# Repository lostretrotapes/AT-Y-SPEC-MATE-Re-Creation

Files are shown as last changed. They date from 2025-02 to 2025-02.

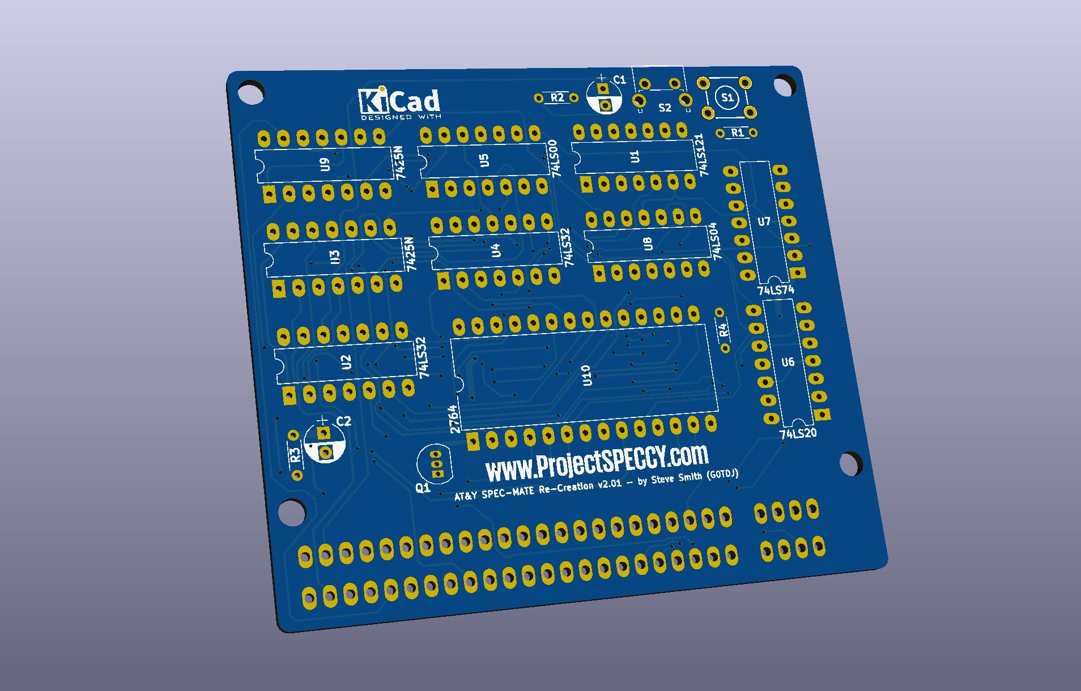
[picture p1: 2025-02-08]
images/Spec-Mate V2.01_FRONT.jpg

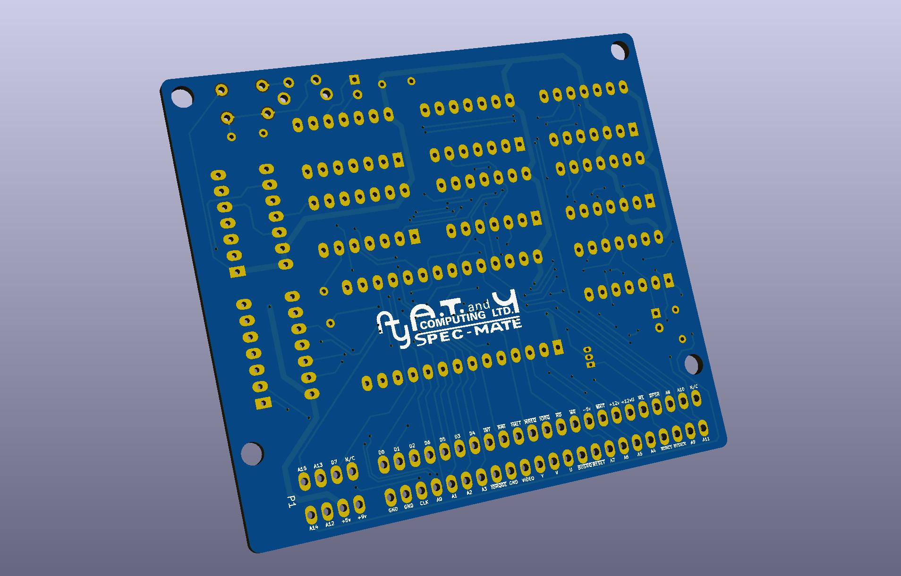
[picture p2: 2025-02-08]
images/Spec-Mate V2.01_BACK.jpg

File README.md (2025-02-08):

# AT-Y-SPEC-MATE-Re-Creation

This is a copy of the recreation that used be hosted at http://projectspeccy.com/projects/ with permission from Steve Smith

Back in the heyday of the Sinclair Spectrum and other 8-bit computers that kick started the home computing movement, I owned a Sinclair Spectrum 48K Plus that I upgraded from my original rubber key Spectrum with a kit from Sinclair. Along with my friends help, I used to hack games for infinite lives etc. This was a very common practice made easier by certian interfaces. The interfaces would freeze the game/program you were running and allow it to be saved to some sort of media, Tape, Sinclair’s own Microdrive or floppy disc for example.

Of course, these interfaces were quite expensive and above the budget of your average schoolboy hacker! I used to hack long-hand, that is to say, from the loader up. Some programs defeated my limited knowledge. Handily though, I had a friend who was into computers and had a more affluent family than I. He got a SPEC-MATE for his birthday. Later on, he loaned it to me so I could capture my game collection to Tape/Microdrive. This was a revelation! And one of the really useful features was that the SPEC-MATE made two files of main memory. This meant that you could load a dissassembler into one part of memory and a half of the programs code in the other. Hacking became exponentially easier!

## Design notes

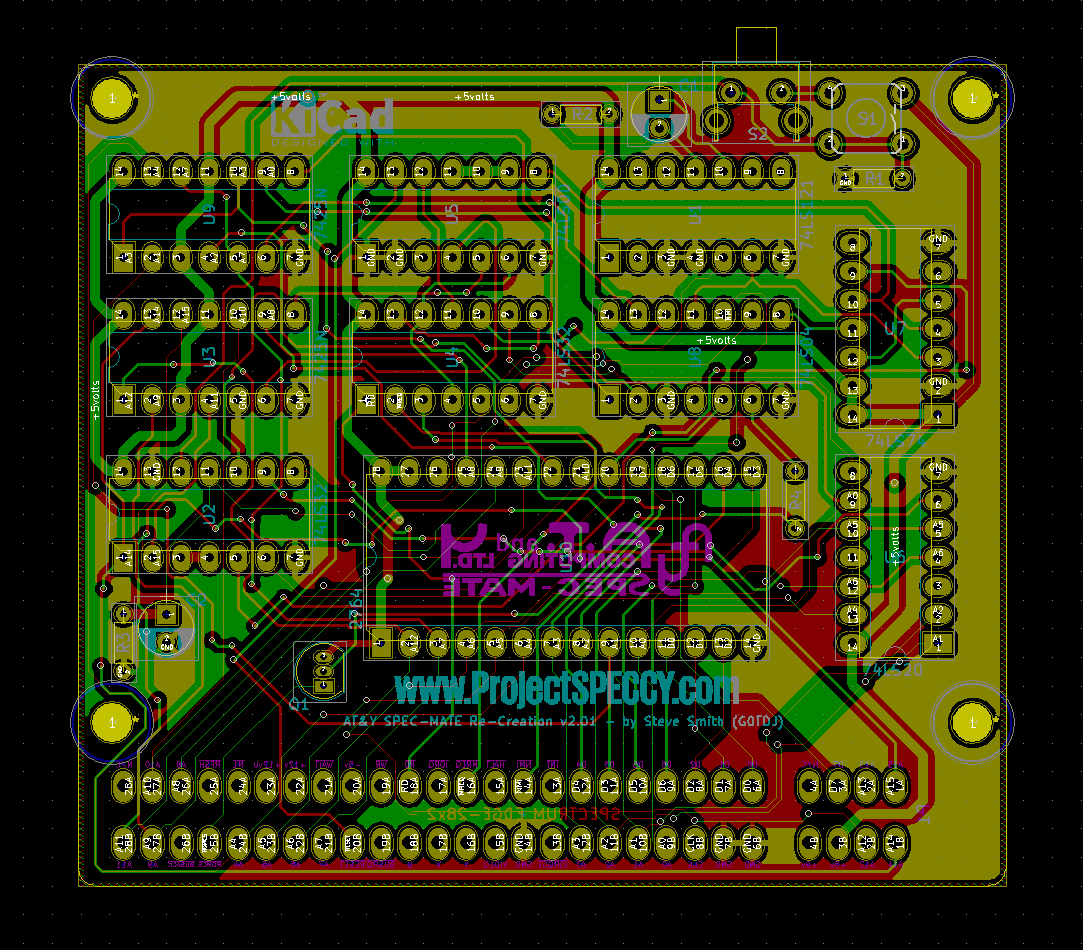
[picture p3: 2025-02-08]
images/Spec-Mate V2.01_KiCad.jpg

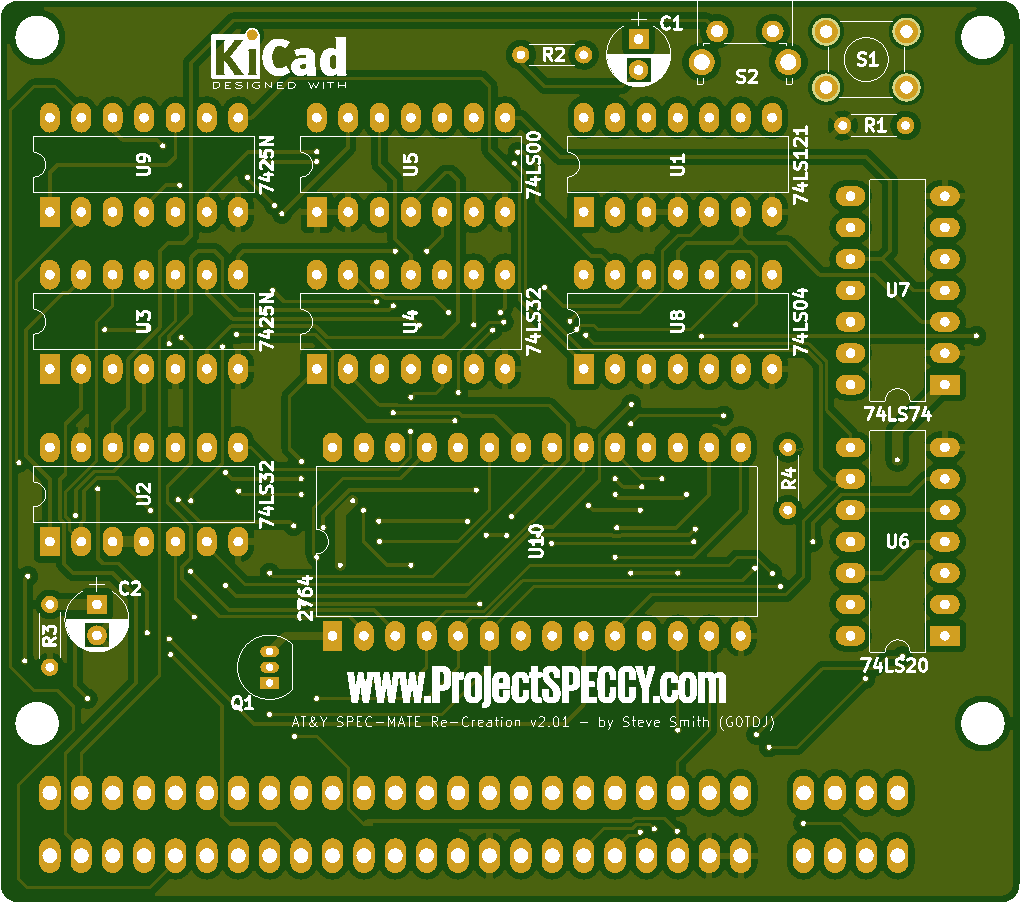
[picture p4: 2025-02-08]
images/Spectrum Spec-Mate v2.01_JLCPCB_Front.png

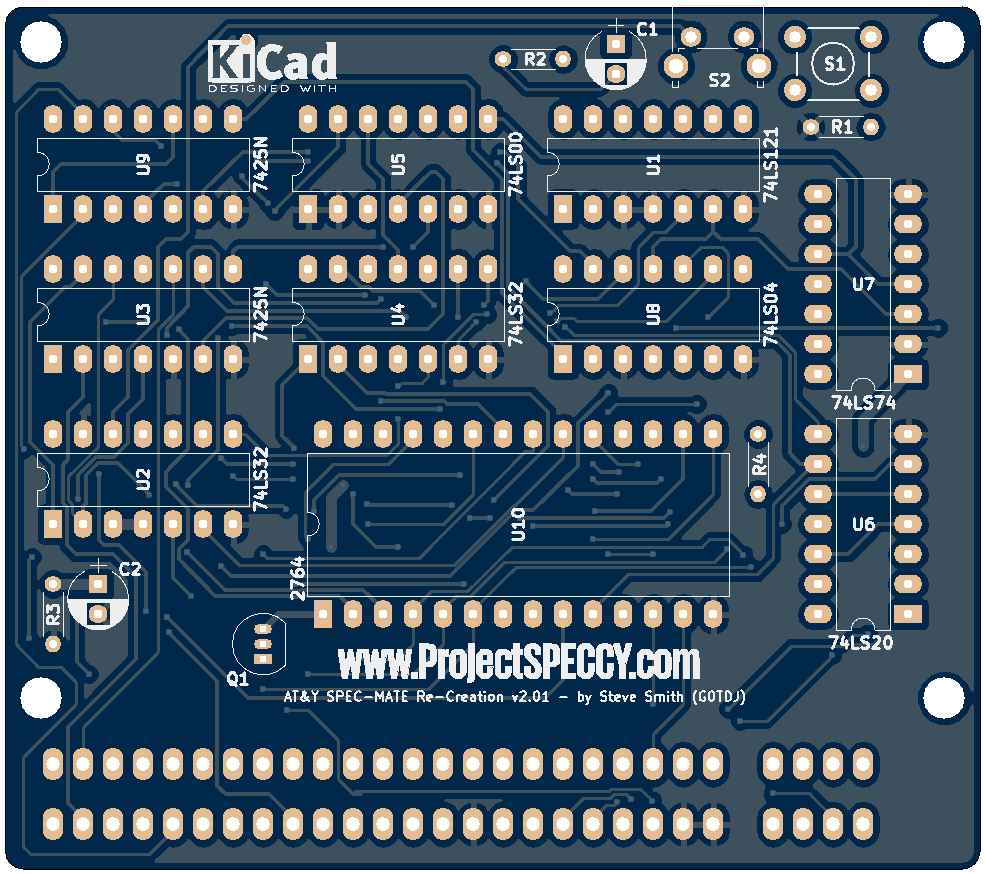
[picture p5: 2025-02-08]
images/Spectrum Spec-Mate v2.01_Gerblook_Front.png

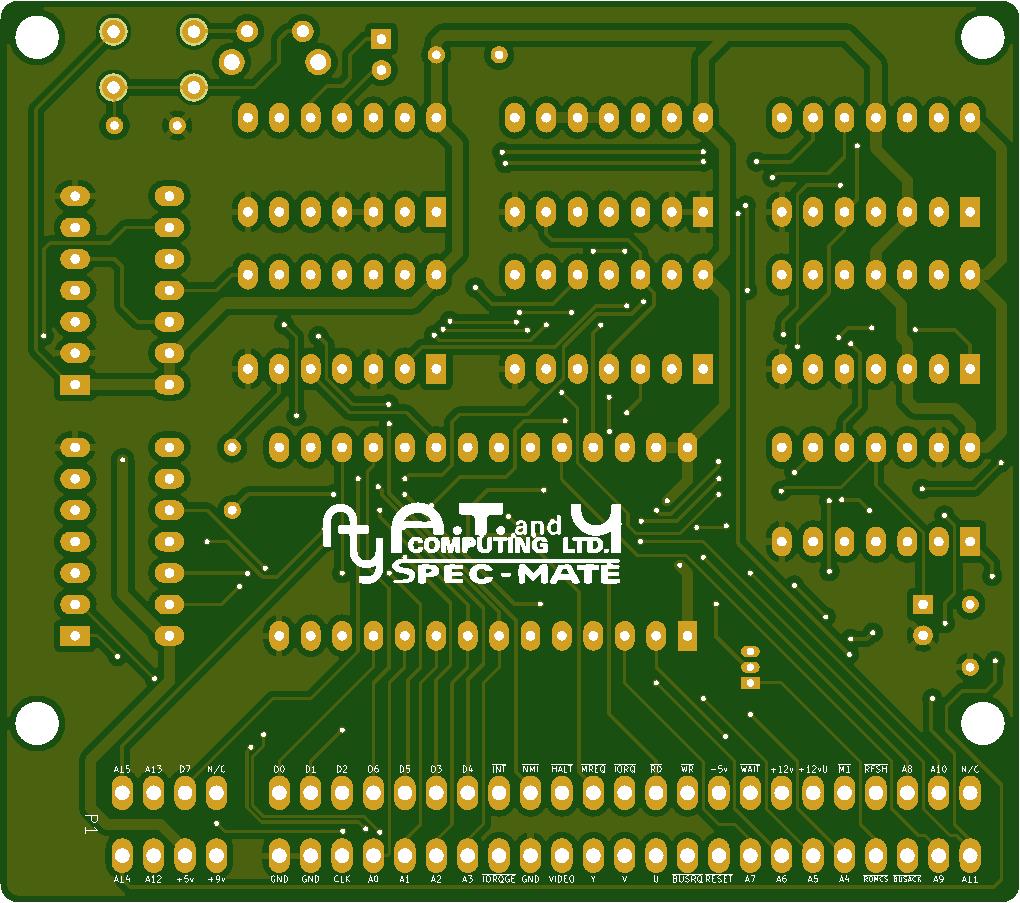
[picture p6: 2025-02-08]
images/Spectrum Spec-Mate v2.01_JLCPCB_Back.png

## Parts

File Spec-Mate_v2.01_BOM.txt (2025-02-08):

Recreated AT&Y SPEC-MATE v2.01

Bill Of Materials

R1	1x 1K 1/4W Resistor

R2	1x 510R 1/4W Resistor

R3	1x 10K 1/4W Resistor

R4	1x 1K1 1/4W Resistor

C1	1x 10u 25v Electrolytic Capacitor

C2	1x 2u2 Electrolytic Capacitor

U1	1x 74LS121

U2/4	2x 74LS32

U3/9	2x SN7425

U5	1x 74LS00

U6	1x 74LS20

U7	1x 74LS74

U8	1x 74LS04

U10	1x 2764 EPROM

Q1	1x 2N2222A Transistor

S1	1x Horizontal Tact Switch (Optional)

S2	1x Right Angle Tact Switch

P1	1x 28x2 Pin Spectrum Edge Connector with slot in pos. 5.

*** www.ProjectSPECCY.com ***

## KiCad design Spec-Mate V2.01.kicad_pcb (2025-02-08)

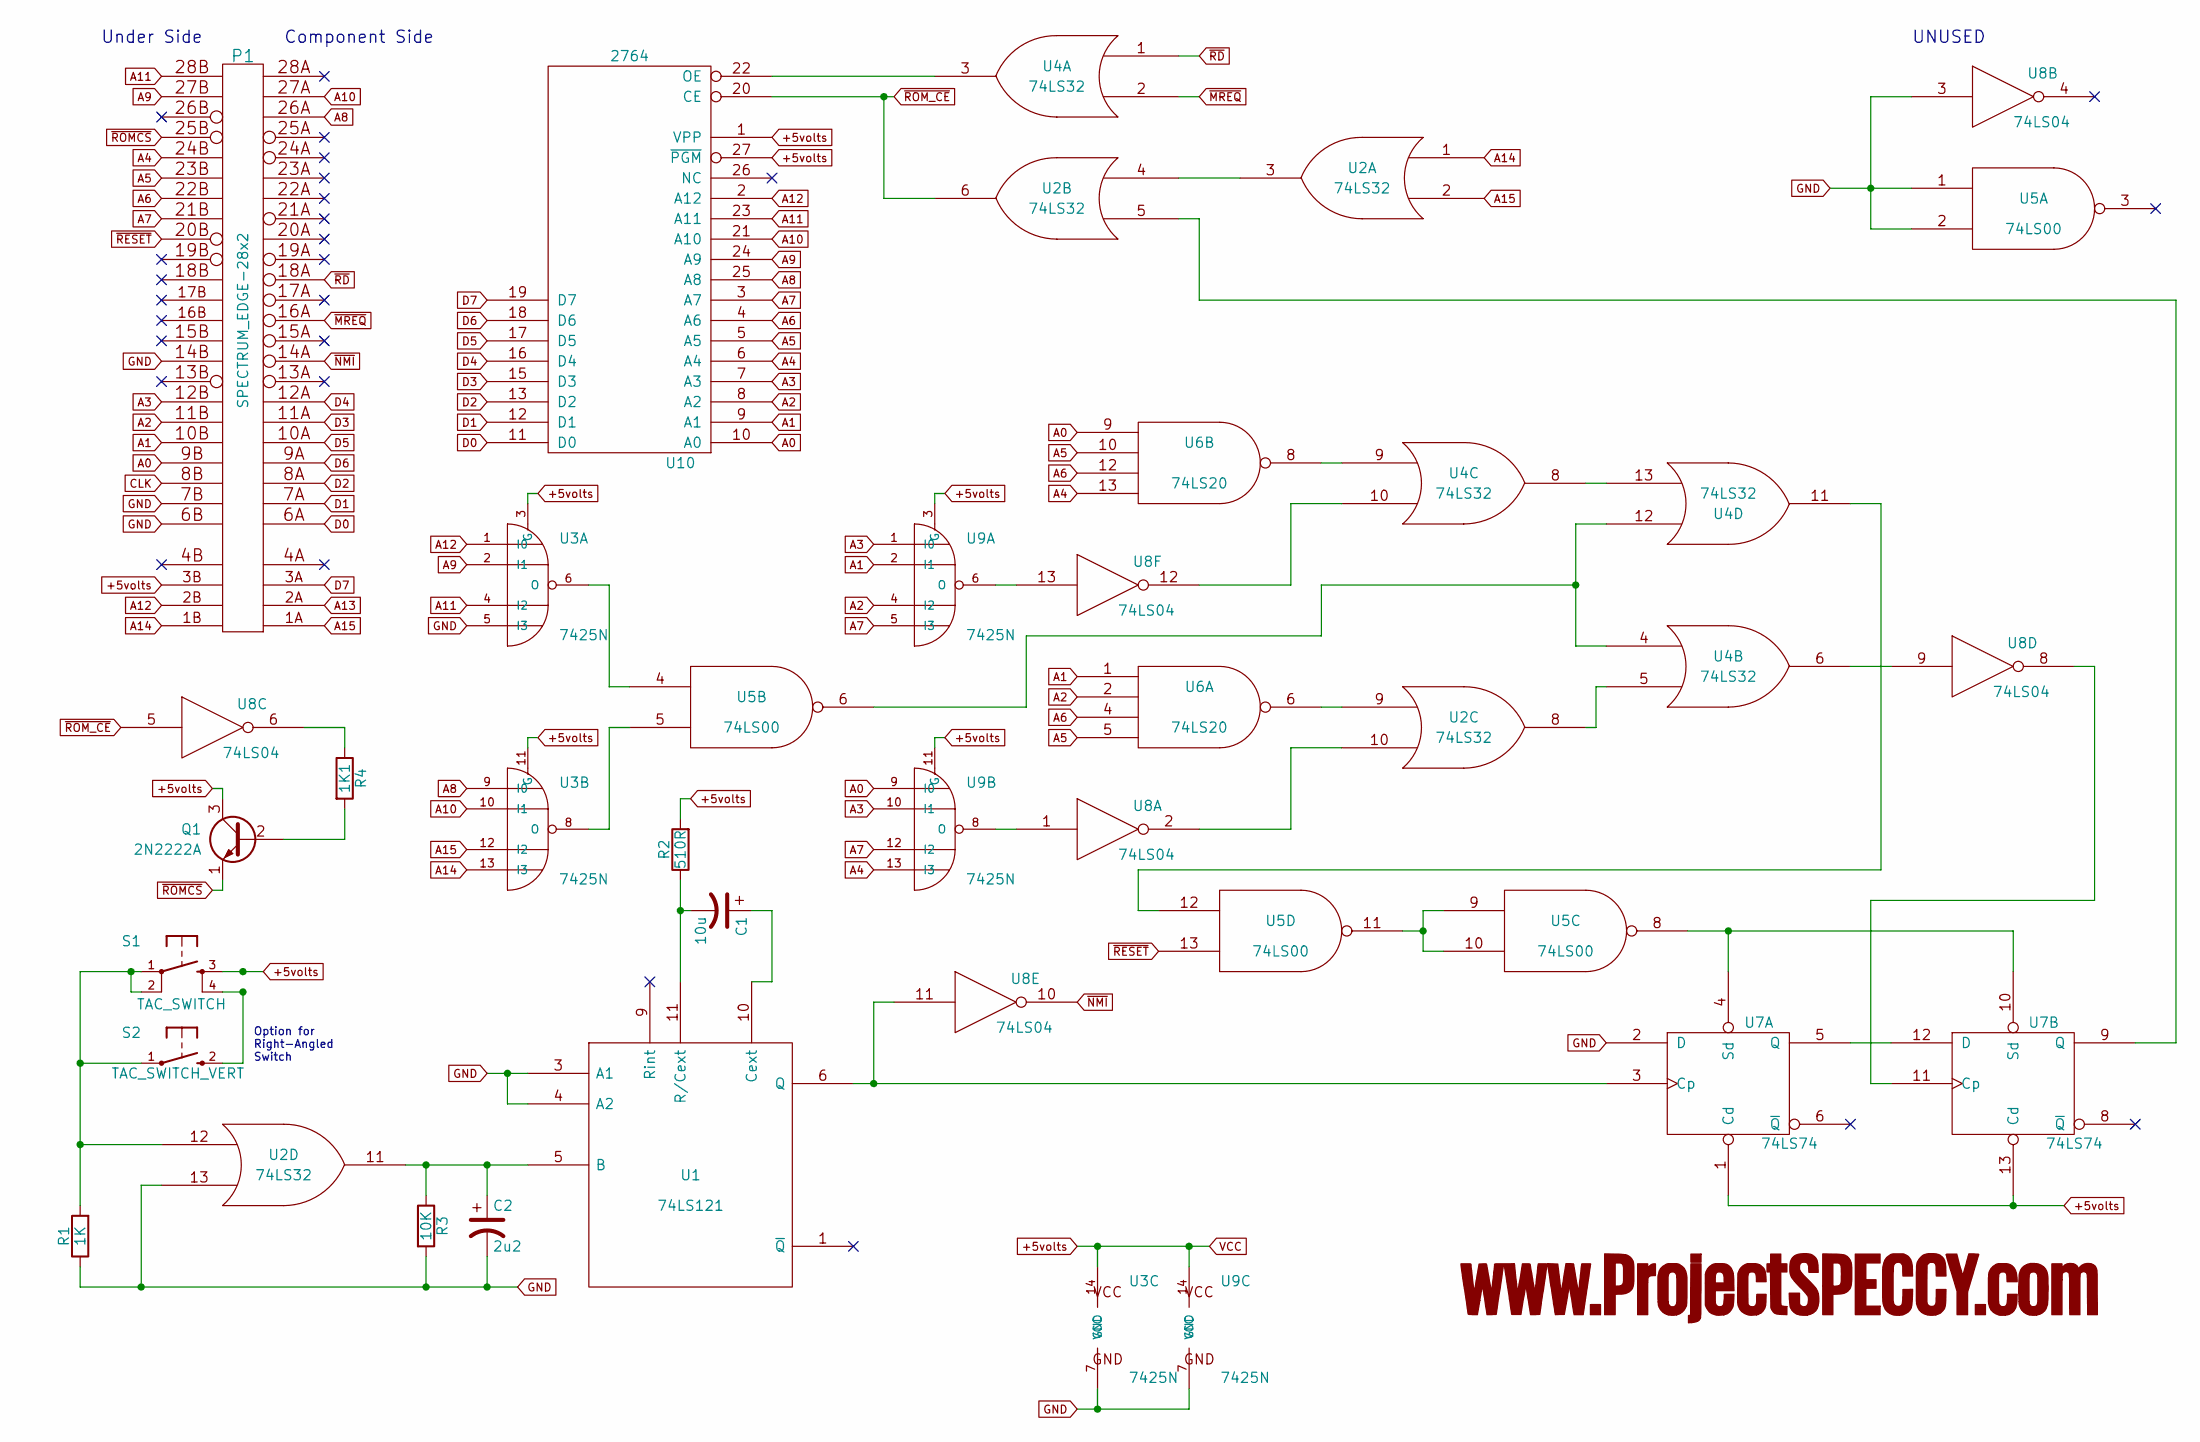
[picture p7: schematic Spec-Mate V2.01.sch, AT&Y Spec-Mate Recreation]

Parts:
C1: 10u; CP_Radial_D5.0mm_P2.50mm
C2: 2u2; CP_Radial_D5.0mm_P2.50mm
P1: SPECTRUM_EDGE-28x2; Spectrum_Edge_Connector
Q1: 2N2222A; TO-92_Inline_Narrow_Oval
R1: 1K; R_Axial_DIN0204_L3.6mm_D1.6mm_P5.08mm_Horizontal
R2: 510R; R_Axial_DIN0204_L3.6mm_D1.6mm_P5.08mm_Horizontal
R3: 10K; R_Axial_DIN0204_L3.6mm_D1.6mm_P5.08mm_Horizontal
R4: 1K1; R_Axial_DIN0204_L3.6mm_D1.6mm_P5.08mm_Horizontal
S1: TAC_SWITCH; TACTILE-PTH
S2: TAC_SWITCH_VERT; SW_Tactile_SPST_Angled_PTS645Vx58-2LFS
U1: 74LS121; DIP-14_W7.62mm_LongPads
U2, U4: 74LS32; DIP-14_W7.62mm_LongPads
U3, U9: 7425N; DIP-14_W7.62mm_LongPads
U5: 74LS00; DIP-14_W7.62mm_LongPads
U6: 74LS20; DIP-14_W7.62mm_LongPads
U7: 74LS74; DIP-14_W7.62mm_LongPads
U8: 74LS04; DIP-14_W7.62mm_LongPads
U10: 2764; DIP-28_W15.24mm_LongPads

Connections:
+5volts: P1.3B (+5volts), Q1.3 (C), R2.2, S1.3, U1.14 (VCC), U2.14 (VCC), U3.3 (G), U3.11 (G), U3.14 (VCC), U4.14 (VCC), U5.14 (VCC), U6.14 (VCC), U7.1 (Cd), U7.13 (Cd), U7.14 (VCC), U8.14 (VCC), U9.3 (G), U9.11 (G), U9.14 (VCC), U10.1 (VPP), U10.27 (~PGM), U10.28 (VCC)
A0: P1.9B (A0), U6.9, U9.9 (I0), U10.10 (A0)
A1: P1.10B (A1), U6.1, U9.2 (I1), U10.9 (A1)
A2: P1.11B (A2), U6.2, U9.4 (I2), U10.8 (A2)
A3: P1.12B (A3), U9.1 (I0), U9.10 (I1), U10.7 (A3)
A4: P1.24B (A4), U6.13, U9.13 (I3), U10.6 (A4)
A5: P1.23B (A5), U6.5, U6.10, U10.5 (A5)
A6: P1.22B (A6), U6.4, U6.12, U10.4 (A6)
A7: P1.21B (A7), U9.5 (I3), U9.12 (I2), U10.3 (A7)
A8: P1.26A (A8), U3.9 (I0), U10.25 (A8)
A9: P1.27B (A9), U3.2 (I1), U10.24 (A9)
A10: P1.27A (A10), U3.10 (I1), U10.21 (A10)
A11: P1.28B (A11), U3.4 (I2), U10.23 (A11)
A12: P1.2B (A12), U3.1 (I0), U10.2 (A12)
A13: P1.2A (A13)
A14: P1.1B (A14), U2.1, U3.13 (I3)
A15: P1.1A (A15), U2.2, U3.12 (I2)
CLK: P1.8B (CLK)
D0: P1.6A (D0), U10.11 (D0)
D1: P1.7A (D1), U10.12 (D1)
D2: P1.8A (D2), U10.13 (D2)
D3: P1.11A (D3), U10.15 (D3)
D4: P1.12A (D4), U10.16 (D4)
D5: P1.10A (D5), U10.17 (D5)
D6: P1.9A (D6), U10.18 (D6)
D7: P1.3A (D7), U10.19 (D7)
GND: C2.2, P1.6B (GND), P1.7B (GND), P1.14B (GND), R1.1, R3.2, U1.3 (A1), U1.4 (A2), U1.7 (GND), U2.7 (GND), U2.13, U3.5 (I3), U3.7 (GND), U4.7 (GND), U5.1, U5.2, U5.7 (GND), U6.7 (GND), U7.2 (D), U7.7 (GND), U8.3, U8.7 (GND), U9.7 (GND), U10.14 (GND)
unnamed: C1.1, U1.10 (Cext)
unnamed: C1.2, R2.1, U1.11 (R/Cext)
unnamed: C2.1, R3.1, U1.5 (B), U2.11
unnamed: Q1.2 (B), R4.2
unnamed: R1.2, S1.1, S1.2, S2.1, U2.12
unnamed: R4.1, U8.6
unnamed: S1.4, S2.2
unnamed: U1.6 (Q), U7.3 (Cp), U8.11
unnamed: U2.3, U2.4
unnamed: U2.5, U7.9 (Q)
unnamed: U2.8, U4.5
unnamed: U2.9, U6.6
unnamed: U2.10, U8.2
unnamed: U3.6 (O), U5.4
unnamed: U3.8 (O), U5.5
unnamed: U4.6, U8.9
unnamed: U4.9, U6.8
unnamed: U4.10, U8.12
unnamed: U4.11, U5.12
unnamed: U4.4, U4.12, U5.6
unnamed: U4.8, U4.13
unnamed: U5.8, U7.4 (Sd), U7.10 (Sd)
unnamed: U5.9, U5.10, U5.11
unnamed: U7.11 (Cp), U8.8
unnamed: U7.5 (Q), U7.12 (D)
unnamed: U8.1, U9.8 (O)
unnamed: U8.13, U9.6 (O)
unnamed: U4.3, U10.22 (OE)
~MREQ: P1.16A (~MREQ), U4.2
~NMI: P1.14A (~NMI), U8.10
~RD: P1.18A (~RD), U4.1
~RESET: P1.20B (~RESET), U5.13
~ROMCS: P1.25B (~ROMCS), Q1.1 (E)
~ROM_CE: U2.6, U8.5, U10.20 (CE)

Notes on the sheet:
Under Side
Component Side
UNUSED
Option for Right-Angled Switch

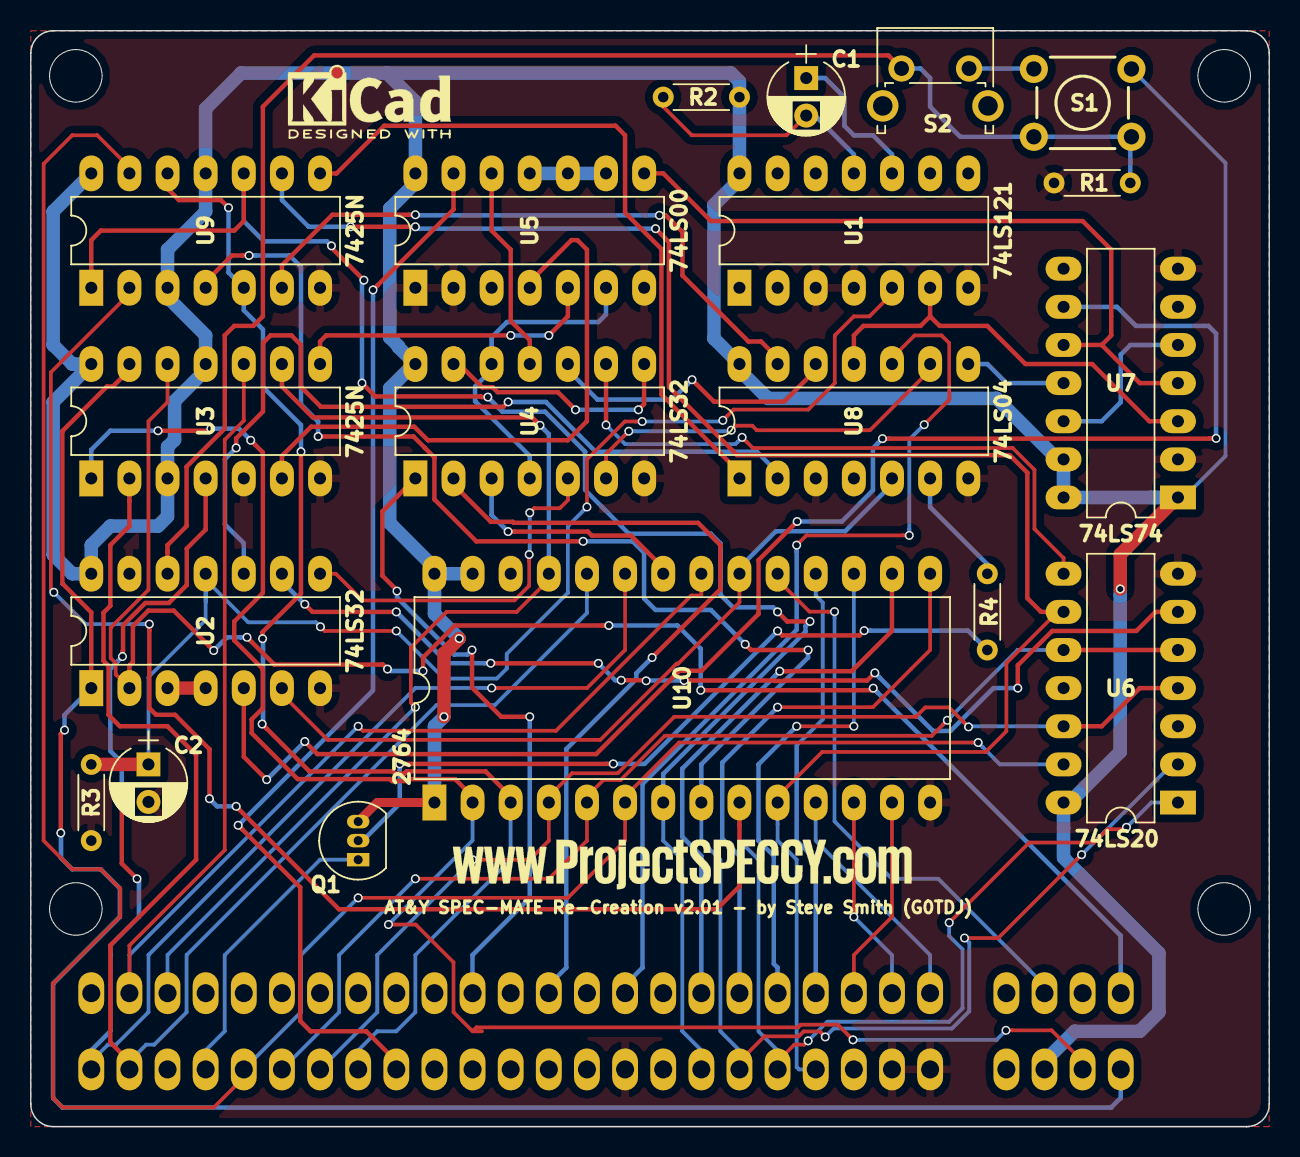
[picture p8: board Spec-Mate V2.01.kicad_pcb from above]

Board: 2 copper layers, 82.5 x 73.0 mm, 20 parts (1 on the bottom side), 59 nets.

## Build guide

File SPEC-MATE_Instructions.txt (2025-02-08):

SPEC-MATE

For Spectrum software transfer to

DISCDRIVE*MICRODRIVE*WAFADRIVE*TAPE*SPRINT DOUBLESPEED

INSTRUCTION MANUAL.

With the purchase of this SPEC-MATE your transfer problems are over! Please read these instructions carefully and you will discover how quickly you will be operating this unique interface.

WHY IS THE SPEC-MATE NECESSARY?

SPEC-MATE enables you to transfer any software to fast loading systems as mentioned above at the touch of a button!

QUICK REFERENCE GUIDE FOR KEYS USED WITH SPEC-MATE

BLACK BORDER MODE

t = save to tape

m = save to microdrive

d = save to disc drive (NB this applies to Beta Interface Only)

w = save to wafadrive

f =  save 'FAST' to tape (i.e. twice normal tape speed)

0 = remove attirbutes

RED BORDER MODE

n = normal save with one screen

s = screenless save

a = save part A of program (with double screen)

b = save part B of program (with double screen)

BLUE BORDER MODE

1 = use top part of screen for *SPEC-MATE* data

2 = use middle part of screen for *SPEC-MATE* data

2 = use bottom part of screen for *SPEC-MATE* data

MAGENTA BORDER MODE

Type the name of the program. Press 'ENTER' to save

GETTING STARTED

THE PROCEDURE USING MICRODRIVE AS AN EXAMPLE

In nearly all cases the following procedure will work every single time. Details of how to tailor and save to your own particular needs are given further on in this manual. This first worked example is for a save to microdrive. Refer to 'Transfer to other systems' section on to see how to adapt it to your storage device.

ENSURE YOUR MAINS SUPPLY IS OFF BEFORE FITTING SPEC-MATE TO YOUR SPECTRUM

1) Push SPEC-MATE onto the edge connector found at the rear of your SPECTRUM and reconnect the mains supply to your computer.

2) Place a blank formatted cartridge in the microdrive and load the cassette software you wish to transfer.

3) When it has loaded press the red button on SPECMATE (The border will flash for a second and the program will be 'frozen' with BLACK BORDER)

4) Press 'm' for a microdrive save (BORDER goes RED)

5) Press 'n' to signify normal save (BORDER goes BLUE)

6) Press '2' (Border goes MAGENTA) N.B. This saves the SPEC-MATE working data to the middle part of the screen.

7) Type in the name with which your program will be saved, ensuring the name you choose does not already exist on the cartridge - maximum 9 characters (a BEEP sounds with every key press).

8) Press 'ENTER' and the program will now transfer to your microdrive!

On completion the program 'unfreezes' and continues to run normally without the need to load your back-up. On rare occasions you may find that this does not happen wiich means that your back-up will also not function. If so please read the rest of this manual for details on how to modify the above procedure paying particular attention to the 'Problem' section.

TAPE (& SPRINT) - The procedure for back-up to tape is the same as that shown in the 'Getting Started' example except that: SPRINT USERS - DISCONNECT SPRINT BEFORE ATTACHING SPEC-MATE TO YOUR SPECTRUM

A) At step 4 press 't'

B) At step 7 the maximum number of characters allowed in the naming is 10.

C) After step 7 remember to start recording before proceeding to step 8.

The resulting tape back-up will now ALSO be compatible with the CHALLENGE SPRINT loading system.

DOUBLE SPEED TAPE BACK-UP - The procedure for making a tape back-upthat will subsequently load at double speed is the same as in the 'Getting Started' example except that:

A) At step 4 press 'f' and you will automatically be taken to step 6.

B) At step 7 the maximum number of characters allowed in the naming is 10.

NOTE FOR ALL USERS

i) Any back-up you make to any storage device will subsequently load INDEPENDANTLY of the SPEC-MATE interface allowing you to use any peripheral you wish.

ii) When naming a program you may use all the Spectrums symbols as SPEC-MATE alows you to obtain Shifted L Mode symbols by just pressing Symbol Shift. For example you can obtain a square bracket on the 'U' key by holding down Symbol Shift/U.

iii) You can reset the computer at any stage when SPEC-MATE is attached.

iv) Please do not use SPEC-MATE's powerful utulities to pirate software!

FURTHER INFORMATION

'FREEZING' POINT - see step 3 in 'Getting Started' - In most cases yoiu can 'freeze' the program at the options page i.e. the part which asks you to select KEMPSTON, KEYBOARD etc. However in some cases you may find the back-up does not work. Try 'freezing' at a different point e.g. at the 'GAME OVER' or 'HIGH SCORE TABLE' stage or if all else failseven in the middle of the program (It is very unlikely but you may need to refer to 'The 0 Key' section below).

RED BORDER MODE - (This section does not apply to Wafadrive users) A program usually has a loading screen. You can opt to save this or do away with it altogether. The trade-off is on the amount of space you use on your drive or tape and the time it takes to load. Remember a spectrum screen picture uses about 7K of memory space. You have the following options:

1) SAVING WITH A SINGLE SCREEN: (complete back-up uses 48K of storage space). You save the program with the screen you 'froze' at. Follow the procedure in the 'Getting Started' example.

2) SAVING WITH TWO SCREENS: (55K). You save the screen you 'froze' at  AND (if you think it is pretty enough!) the original loading screen. This is what you do - 

A) Load the program until you can see the complete loading screen picture on your T.V.

B) Interrupt the loading process by pressing the red button.

C) Press 'm', 't' or 'd' as required.

D) Press 'a' (BORDER goes MAGENTA)

E) Type in the name of the program

F) Tape users start recording. Press 'ENTER' to save first screen.

G) Reset the computer, rewind the cassette and begin loading from the beginning again.

H) When the complete program has loaded press the red button again.

I) Press 'm', 't' or 'd' as required.

J) Press 'b' (BORDER goes BLUE)

K) Tape users start recording. Press '2' (for other options see 'Bluse Border' section of this manual).

FOR TAPE USERS THE OPERATION IS NOW COMPLETE

L) Type in the SAME name as you typed in step E

M) Press 'ENTER' to save second part of program.

TWO SCREEN SAVING IS NOW COMPLETE

3) SAVING WITHOUT A SCREEN: (43K) YOu save the program so that it loads with a blank screen. This means that you must be careful where you 'freeze'. Try to do it where the program has a 'press any key to continue' option or just before it moves to another section by itself. Remember a screenless back-up will have no instructions on the screen when it loads The advantage is the saving of storage space. For example you can fit two programs on a microdrive cartridge.

This is what you do - 

A) After 'freezing' press 'm', 't' or 'd' as required.

B) Press 's' (BORDER goes MAGENTA)

C) Type in the name and press 'ENTER' as you have done in other examples.

BLUE BORDER MODE - (This section does not apply to Wafadrive users). When you pressed '2' in the 'Getting Started' example you probably noticed that the middle part of the screen picture was changed (For tape users only one line was affected). This is where SPEC-MATE strores its working data. You may however wish to change a different part of the picture. Pressing '1' will cover the top third of the screen and '3' the bottom third. Thus, you can decide which parts ot the picture you wish to keep intact. Just remember SPEC-MATE always needs to cover one third of the screen. YOu select the third by using '1', '2' or '3' in BLUE BORDER MODE.

THE '0' KEY

On very rare occasions a particular third of the screen MUST NOT be changed because the program also stores working data 'hidden' in the screen picture and this data must be preserved intact in your back-up or it will not work at all. This is where the '0' key comes in. It enables you to discover if any of this 'hidden' code exists and if so which third of the screen it lies in. When you press '0' in BLACK BORDER MODE (see 'Quick Reference Guide) the colours will be removed from the screen picture where you 'froze' the program. This enables you to see the #hidden' data. If there is any present you will see a series of little black lines, dots or shapes on the screen. After you have examined the screen you can press any key to 'unfreeze' and return to the program in order to continue the back-up procedure. Use the '1', '2' or '3' keys as described above to ensure that this 'hidden' data in not disturbed. Please let us emphasise that this will only be necessary on very rare occasions. We have only included this option so that you can transfer all programs in any way you wish making SPEC-MATE a very powerful tool indeed.

HINTS AND TIPS

This section outlines some other things you can do with SPEC-MATE apart from just transferring your programs.

You can save any screen picture at any point during play by following the in the first part of the Red Border Mode 'saving with two screens'

For the more advanced user......

If you use a program that handles files you can transfer the whole program with it's files. For example, if you are a discdrive user and want to use Tasword II, there is no need to adapt Tasword, just transfer the whole program together with the file you are using.

* You can add pokes to your back-up by pressing break as soon as the screen goes black when you begin loading. If you now change the 'INK' to 9 and 'LIST' the basic program loader you can add a poke statement

N.B. Any normal spectrum error report such as 'microdrive not present' or reading to a write file' etc will crash the spectrum when SPEC-MATE is in use.

TRANSFER TO OTHER SYSTEMS

DISC DRIVE - The procedure for back-up to disc drive is the same as shown in the 'Getting Started' example except that:

A) Ensure that you do not use a password on your disc as this interferes with the operation of SPEC-MATE.

B) At step 4 press 'd'

C) When naming your back-up in step 7 the maximum number of characters allowed is 6

WAFADRIVE - The procedure to back-up for WAFA is the same as that shown in the 'Getting Started' example except that:

A) Ensure that you are using a wafer large enough to take the back-up which will occupy 48K of space.

B) At step 4 press 'w' and you will AUTOMATICALLY be taken to ste 7.

C) After step 8 SPEC-MATE will make a special save to your wafadrive. Programs are always in this way because the wafadrive itself uses a large amount of working space. In consequence much of this manual will not apply to wafadrive users BUT you should pay SPECIAL ATTENTION to the 'Freezing point' and 'Saving without a screen' sections of this manual and save your back-ups accordingly.

PROBLEMS

If for any reason transfer of your program fails you will find that on completion the program does not 'unfreeze' and carry on running as described above. If this happens check the following:

1) There is always the possibility that the original software you are trying to load is faulty or that you had the volume control set at an innapropriate level or that your tape head is in need of attention. In general if the original does not load then obvioulsy SPEC-MATE cannot transfer it! Check your original.

2) Try 'freezing' the program at a different point as described in the 'FREEZING' POINT section of this manual.

3) Try using an alternative number in BLUE BORDER MODE i.e. if you used '1' try '2' or '3' instead.

IF ALL ELSE FAILS - You can contact us on: 01-733 6175 (Evenings are best) and we will try to sort out your problem.

------------------------------------------------------------

Notes: I have typed these instructions pretty much verbatim from a scanned copy of the original (Many thanks Michael!) and I stayed true to the way it was written, grammar, punctuation and all with only minor changes.

I have done this as a compainion to my own recreation of the SPEC-MATE interface, the details of which can be found on www.ProjectSPECCY.com for anyone to utilise. Should you decide to build one, you need only download the GERBER files and send them to a fabricator to have PCBs made. You can then obtain the required components and build your own.

I have fond memories of this interface. I loaned one from a friend back in the heyday of the Spectrum and used it to hack lots of games along with a microdrive, DEVPAC Monitor and later Laser Genius Monitor. Although it didn't work with all games, it did with most of the ones I was interested in. I can remember vividly trying to press the SPEC-MATE's 'Red Button' to catch Knightlore as it's loading screen dissapeared but before it's main menu appeared to obtain the perfect back-up. It took mutiple attempts! Those were good times.

Steve Smith - 30/12/2018 - www.ProjectSPECCY.com
